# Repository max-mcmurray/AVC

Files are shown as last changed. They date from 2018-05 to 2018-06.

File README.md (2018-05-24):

# Readme:

### Week 1:

- [x] **[All]**: Make GitHub accounts and get plan done
- [x] Josh: Determine formatting for AV code
- [x] Penny: Arrange team meetings
- [x] Penny: Make draft of plan into the final copy
- [x] Toby, Ben: Get basic build of AV planned/put together
- [x] Max: Set up GitHub
- [x] Ben: Make GitHub account

### Week 2:

- [ ] ~~**[All]**: Book CO242A every Thursday~~ This is no longer needed
- [x] Josh: Program ~~sensors and~~ basic movement into AV - Sensors have not yet been added to the AV
- [x] Josh: Program and test the completion of quadrant 2
- [x] Josh: Assign methods to each member of the group
- [x] Toby, Ben: Refine build of AV
- [x] Ben: Program methods for basic movement
- [x] Penny: Get everyone organised and plan for next week
- [x] Penny: Document progress
- [x] Max: Update GitHub with developments

### Week 3:

- [x] Josh: Ensure AV can complete quadrants 1, 2 and 3
- [x] Josh: Test methods as completed by other members
- [x] Penny: Assess team member progress, organise team meeting and plan for next week
- [x] Penny: Write method to open gate
- [x] Penny: Document progress to date
- [x] Max: Update GitHub with development and check over AV design
- [x] Max: Write method to complete line maze
- [x] Toby, Ben: Add sensors to the AV build
- [x] Toby, Ben: Finish the AV build with all the required parts
- [x] Toby: Write method to complete walled maze

### Week 4:

- [x] Josh: Ensure AV can complete course, finalise and optimise code
- [x] Penny: Assessing full team progress against expected results.
- [x] Penny: Implement necessary changes. Bug testing and debugging code
- [x] Max: Update GitHub with development and test AV thoroughly in maze
- [x] Toby, Ben: Make adjustments and finalise AV build

### Week 5:

- [ ] **[All]**: Complete final test of AV - Five attempts and fifteen minutes to complete
- [ ] **[All]**: Put results in report

### Week 6:

- [ ] **[All]**: Continue writing report

### Week 7:

- [ ] **[All]**: Hand in report

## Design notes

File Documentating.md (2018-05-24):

### 03/05
- Created design for base
- Printed base
- Printing of base failed (fell over in the printer)

### 04/05
- Team meeting to prepare and finish AVC plan

### 05/05 12.20
- Discussed methods in code and general 
- Created outline of methods
- Josh wrote goForward
- Josh created makefile
- Changed GitHub to use one branch
- Ben wrote turnLeft
- Penny improved plan
- Josh wrote detectLine
- Toby wrote detectLineToby
- Josh wrote turnRight
- Josh wrote pivotLeft

### 07/05 
- Ben attached the poles connecting the motherboards
- Ben attached the base to the motherboards
- Ben attached the left and right wheels to the base
- The camera was connected to the top base
- The marble holder was printed

### 09/05 
- Attached the marble holder to the base
- Testing basic movement: functionality of the left and right motor
- Josh and Toby modified code to enable some movement throughout maze
- Battery holder was connected to the top base 
- Testing the robot on the maze and debugging issues 
- Right motor is not functioning properly 
- Right motor problem has been fixed
- Testing code on robot and making adjustments to fix errors
- Re-testing the robot on the maze using modified code
- Errors were identified both in code and in hardware: Initially, we thought the robot had followed the white line but could not correct itself when the colour black was scanned by the camera. We concluded that our code needed to be altered (by decreasing the int defaultMicroSec and int defaultSpeed) in order for the robot to change direction in time. After multiple testing and debugging, we reached the final conclusion that in fact one of the motors is slower than the other and that there were errors in our code
- Re-testing the robot on the maze using modified code: The robot followed the white line but turned at a slow speed and went off track but could not correct itself
- Re-tested the robot on the maze using modified code: (EXTREME PROGRESS) The robot followed the white line at a slow speed and could turn at corners properly (without going off track) after camera angle was changed. 
- Re-tested the robot on the maze using modified code: The sample speed was changed but the robot was moving extremely slow on the maze. 
- Re-tested the robot on the maze using modified code: The sample speed, defaultSpeed and other speed were adjusted multiple times. The robot followed the white line properly at a slightly faster pace. More soldering needs to be done. 

### 10/05
- Attached the switch to the battery and base
- Applied modified code to robot
- Testing the robot on the maze: Speed is too slow therefore the robot isn't moving. The defaultSpeed and sample speed have been adjusted. 
- Re-testing the robot on the maze: Sample speed is too slow therefore the robot isn't reading the white line fast enough for the speed it is moving at. The sample speed has been adjusted. 
- Re-testing the robot on the maze: Turn speed is too fast but defaultSpeed is ok. The robot is turning too fast for the defaultSpeed therefore it is going off track. Adjustment must be made to turn speed. 
- Re-testing the robot on the maze: (EXTREME DRAWBACK) Adjustments have been made but the robot is no longer following the white line. defaultSpeed and sample speed has been adjusted back to the original values.
- Re-testing the robot on the maze: The robot can now follow the white line but not as precisely as before. Improvements need to be made in order for the robot to correct itself (reverse etc.) when the camera has scanned black. 
- Re-testing the robot on the maze: The robot can follow the white line properly but at certain bends in the maze, the robot cannot turn fast enough therefore the turn speed needs to be increased slightly. 
- Re-testing the robot on the maze: The robot follows the line at a moderate speed but at certain bends in the maze, the robot only sees black therefore it gets confused. Modification has been made in order for the robot to correct itself and reverse when black is detected by the camera.
- Re-testing the robot on the maze: The robot is reversing when required but is not reversing enough therefore the reverse time needs to be increased.
- Re-testing the robot on maze: The robot is reversing still but the reverse speed needs more power therefore the reverse speed needs to be adjusted and the defaultSpeed is increased. 
- Re-testing the robot on maze: The robot is moving through the maze but the turn is too wide therefore the turn speed needs to be adjusted back to our previous value.
- Re-tesing the robot on maze: The robot moved through the maze and turned correctly but the reverse time needs to be increased.
- Re-testing the robot on maze: The robot corrects it self well and breaks at max white but the turn is too wide therefore the turn speed and reverse speed needs to be adjusted. 
- Re-testing the robot on maze: (EXTREMELY GOOD RUN) The robot turns better and corrects itself properly but the turn is still quite wide therefore the defaultSpeed needs to be adjusted for the inside wheel speed.
- Re-testing the robot on maze: (PERFECT RUN) The robot is turning extremely well at a lower speed. Begin programming next part ----> 

### 14/05

- Testing the code to open the first gate
- Adjusting speeds in order for the robot to move and take bends in the maze smoothly
- The gate is opening and the robot is moving through it at an appropriate time. The robot then moves through the maze smoothly.

### 15/05

- Compiled different versions of code and tested it the robot on the maze
- Writing code for quadrant 3: beginning with the code that makes the robot turn at a right angle which includes establishing the values for each variable that is used
- Adjusting the time of the turn so it doesn't turn too fast or too slow
- Testing the robot on maze: The robot is continuously making a 360 degree turn therefore code needs to be looked at again and adjustments need to be made. 

### 16/05

- Cleaned up code so that it is systematic and easy to follow
- Writing code so that the robot stops at the orange line and also clearly makes left and right turns when required
- (EXTREMELY PROMISING) Test run to see if the robot correctly makes left and right turns when required. Adjustments need to be made to the pivotSpeed and defaultSpeed
- (EXTREMELY EXTREMELY PROMISING) The robot is turning fairly correctly when required now we need to put together the code with the master copy so that it runs the maze up to the end of Quadrant 3
- Minor setback after code was put together - robot isn't turning properly like the previous run therefore adjustments are being made to motor speed
- (HIGHLY PROMISING) The robot is moving correctly but the right and left turns are slightly off but the robot has reached the end
- (SUCCESSFUL RUN) The robot is moving correctly from the beginning of the maze to the end of Quadrant 3.

### 18/05

- Printing out the parts to connect the sensors to the robot
- Attaching the front sensor to the robot
- Writing code so that the robot stops at the orange line

### 22/05 

- The sensors are being attached to the robot 
- Testing the sensors

### 23/05

- Originally there were 3 sensors connected to the robot, all of which are long-range sensors. After testing them out, we reached the conclusion that the robot would need one long-range sensor in the front and two-range sensors on the sides in order to move through the maze. 
- The new sensors have been attached to the robot and code for the maze is being tested
- The robot is moving but continuously turns left and hits the wall 
- We are currently stuck in a deep dark hole. Every member is feeling all types of confused. The problem is hard to identify. 
- The plan is to add back sensors to the robot tomorrow and hope for the best

### 24/05

- The plan was to add back sensors to the robot but today we decided to code without them
- Code for Quadrant 4 is successful: minor tweaks have been made to speed so that the robot moves fast and efficiently through the maze
- The full code has been tested on the maze multiple times and we have had many SUCCESSFUL attempts
- The switch has been attached to the top of the robot 
- THRASHER GOT US 100% YAY!

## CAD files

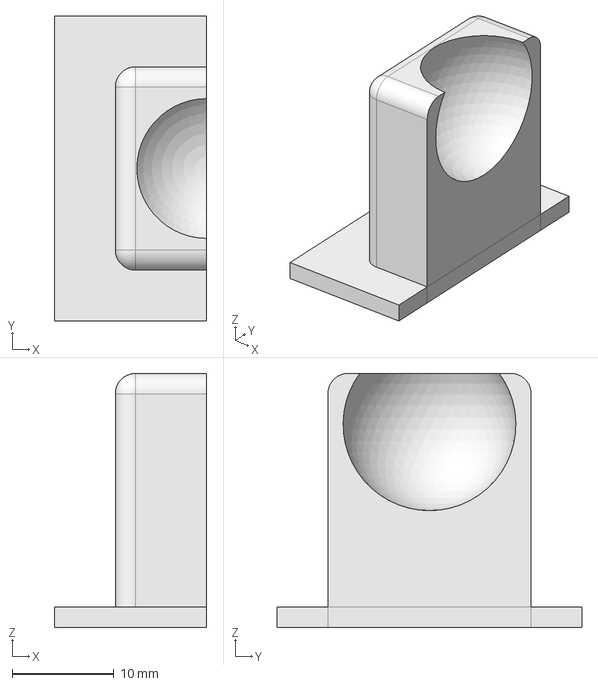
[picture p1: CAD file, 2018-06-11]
3D/Marble-Holder.fcstd
15.0 x 30.0 x 25.0 mm

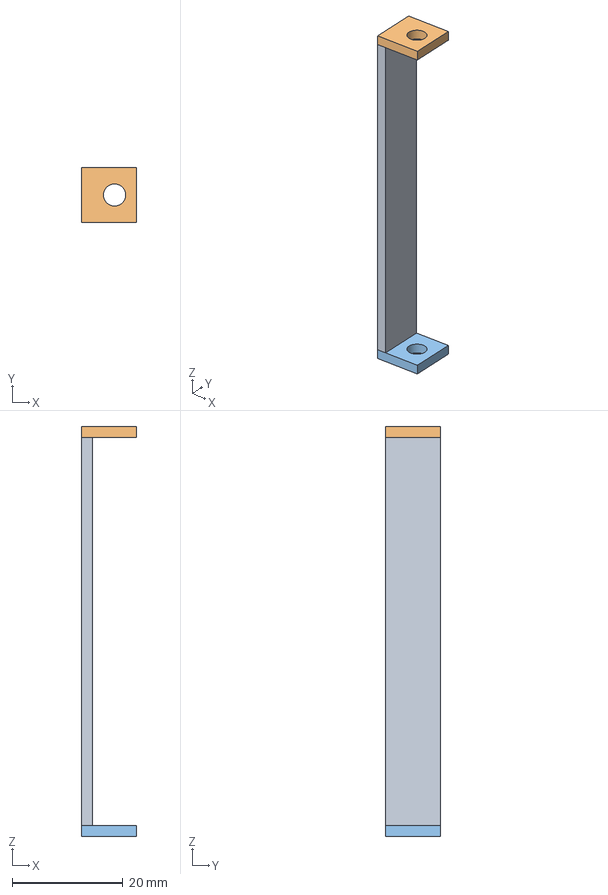
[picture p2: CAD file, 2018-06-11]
3D/IR-Holder-side.fcstd
10.0 x 10.0 x 74.0 mm

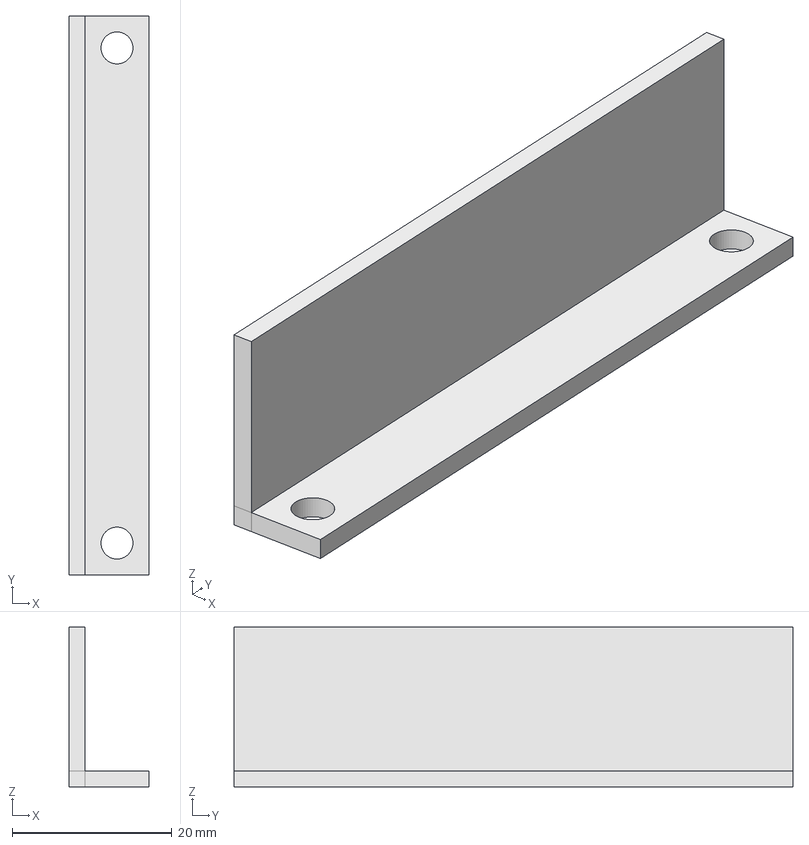
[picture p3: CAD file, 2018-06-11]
3D/IR-Holder-front.fcstd
10.0 x 70.0 x 20.0 mm

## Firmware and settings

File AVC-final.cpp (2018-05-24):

//This program is the intellectual property of TriTeam.
//This program was programmed by Joshua Hindley, Ben Robertson, Max McMurray, Penny Peneueta and Toby Stayner

#include <stdio.h>
#include <time.h>
#include <exception>
#include "E101.h"

/////////////////////////////////////////////////////////////////////
///////////////////////////// VARIABLES /////////////////////////////
/////////////////////////////////////////////////////////////////////

//motor port numbers
int leftMotor = 1;
int rightMotor = 2;

//picture variables
int width = 319;
int height = 239;
int rowToScan = height/2;
int columnToScan = width/2;

//variables for the speed
int straightSpeed = -50;
int reverseSpeed = 50;
int insideWheelSpeed = -25;
int turningWheelSpeed = -60;

//variable for the time (sleep1)
int defaultSec = 0;
int defaultMicroSec  = 2000; 	// 2ms or 0.002 seconds 
int reverseMicroSec = 500000;	// 500ms or 0.5 seconds

//variables for the minimum and maximum color
int maxMin[2];

//variables for determining when to reverse or change quadrant
int blackValue = 100;
int whiteValue = 150;

//variables for pivoting
int rightAngleMSec = 400000; 	// 400ms or 0.4 seconds
double pivotSpeed = -60;

//declaration of all the methods
void openStartGate();
void detectLine();
void lineMaze();
void goForward(int forwardMicroSec);
void reverse(int sec, int microsec);
void turnLeft(int sec, int microsec);
void turnRight(int sec, int microsec);
void pivotLeft(int sec, int microsec, double speed);
void pivotRight(int sec, int microsec, double speed);
double getAmountToTurn(int threshold);
void findMaxAndMin();
void stop();
void navigateWalledMaze();
void centreWallMaze();


/////////////////////////////////////////////////////////////////////
////////////////////////////// METHODS //////////////////////////////
/////////////////////////////////////////////////////////////////////

//main method. determines which method to call
int main()
{
	init();
	//call the openStartGate method to complete quadrant 1
	openStartGate();
	sleep1(0, 200000);
	//call the detectLine method to complete quadrant 2
	detectLine();
	//openStartGate();
	goForward(200000);
	//call the lineMaze method to complete quadrant 3
	lineMaze();
	//openStartGate();
	navigateWalledMaze();
	stop();
	return 0;
}

//opens the gate at the start of the course, completing the first quadrant
//written by Penny Peneueta
void openStartGate()
{
	//variables for connecting to the server
	char server_addr[15] = "130.195.6.196";
	int port = 1024;
	char message[24] = "Please";
	
	//connects to the server, sends a message, receives a message and sends the received message
	connect_to_server(server_addr, port);
	send_to_server(message);
	receive_from_server(message);
	send_to_server(message);
	//prints to the console
	printf("Gate opened.\n");
	printf("******************Quadrant 1 completed.\n\n");
}

//finds where the white line is and calls methods to move the AV stay on the line
//written by Joshua Hindley
void detectLine()
{
	try{
		while(true)
		{
			findMaxAndMin();
			//if all the rowToScan pixels are black
			if(maxMin[0] < blackValue)
			{
				reverse(defaultSec, reverseMicroSec);
			}
			//if all the rowToScan pixels are white
			else if(maxMin[1] > blackValue)
			{
				//print to console
				printf("******************Quadrant 2 completed\n\n");
				return;
			}
			else
			{
				//calculates the threshold and calls the getAmountToTurn method to determine the amount to turn
				int threshold = (maxMin[0] + maxMin[1]) / 2;
				double amountToTurn = getAmountToTurn(threshold);
				if(amountToTurn <= 1000 && amountToTurn >= -1000) //CHANGE THIS VALUE TO CHANGE HOW OFTEN IT TURNS
				{
					goForward(defaultMicroSec);
				}
				else if(amountToTurn > 1000) //turn to the right
				{		
					turnRight(defaultSec, defaultMicroSec);
				}
				else //turn to the left
				{	
					turnLeft(defaultSec, defaultMicroSec);
				}
			}
		}
	}
	catch(const std::exception& e){
		printf("An error occured!\n");
	}
	//set the motor's speeds to zero
	stop();
}

//Follows lines in the form of a maze
//Written by Max 
void lineMaze() 
{
	bool justTurned = false;
    try{
		while(true)
		{
			//set the max and min values
		   	findMaxAndMin();
			//if all the pixels are black
		    if(maxMin[0] < blackValue + 25)
		    {
				if (!justTurned) 
				{
					//pivots to the left
			    	pivotLeft(0, rightAngleMSec / 2, pivotSpeed);
			    	justTurned = true;
			    	sleep1(0, 500000);
				}
				else 
				{
					//pivots to the right twice
			   		pivotRight(0, rightAngleMSec / 2, pivotSpeed);
			    	sleep1(0, 500000);
			    	pivotRight(0, rightAngleMSec / 2, pivotSpeed);
			    	justTurned = false;
			    	sleep1(0, 500000);
				}
		    }
		   	else
		    {
				justTurned = false;
				//calculates the threshold and calls the getAmountToTurn method to determine the amount to turn
				int threshold = (maxMin[0] + maxMin[1]) / 2;
				double amountToTurn = getAmountToTurn(threshold);
				if((amountToTurn <= 20) & (amountToTurn >= -20)) 
				{
			    	goForward(defaultMicroSec);			   
				}
				else if(amountToTurn > 20) //turn to the right
				{
			    	turnRight(defaultSec, defaultMicroSec);			 
				}
				else //turn to the left
				{
			   		turnLeft(defaultSec, defaultMicroSec);
				}
		    }
			//if the centre pixel of the image is orange
		    if( (get_pixel(160, 120, 0) > 150) & (get_pixel(160,120,1) < 80) & (get_pixel(160, 120, 2) < 70))
		    {
				//print to the console
				printf("******************Quadrant 3 completed\n");
				//set the motor speeds to zero
				stop();
				return;
		    }
		}
	}
	//if an error occurs
    catch(const std::exception& e)
	{
		printf("An error occured\n");
	}
	//set the motor speeds to zero
	stop();
}

//follows the left wall of the maze, completing the final quadrant
//written by Toby Stayner

int frontThreshold = 350; // AV considers the robot has a wall in front anything larger than this
int wallThreshold = 450; // AV considers the robot has a wall either side anything larger than this
int noiseConstant; // amount of leeway before the left sensor is no longer considered equal to the right sensor
int forwardAfterTurn = 250000; // amount of time (microsecs) the AV should continue travelling forward once it has made a turn

int left_sensor = 2; // the number ports that the wires are physically connected to
int front_sensor = 1;
int right_sensor = 0;
int adc_reading_left;
int adc_reading_front;
int adc_reading_right;
bool seenRed = false;

void navigateWalledMaze()
{
	printf("Beggining***\n");
	goForward(500000);
	try{
		while(1)
		{
			adc_reading_left = read_analog(left_sensor); // read the sensor values and store them
			adc_reading_front = read_analog(front_sensor);
			adc_reading_right = read_analog(right_sensor);

			take_picture();
			//if the centre pixel of the image is red
		    if((get_pixel(160, 120, 0) > 200) & (get_pixel(160,120,1) < 100) & (get_pixel(160, 120, 2) < 150) & !seenRed)
		    {
				seenRed = true;
				goForward(900000);
				stop();
				adc_reading_front = read_analog(front_sensor);
				//if gate is open
				if((adc_reading_front < 75))
				{
					//while gate is open
					while(adc_reading_front < 75)
					{
						//wait for gate to close
						adc_reading_front = read_analog(front_sensor);
					}
				}
				//while gate is closed
				while(adc_reading_front > 75)
					{
						//wait for gate to open
						adc_reading_front = read_analog(front_sensor);
					}
		    }
			// if there are nearby walls on both sides and can go forward
			if((adc_reading_front < frontThreshold))
			{
				printf("Forward.\n");
				centreWallMaze();
			}

			// if there is a path on the left only
			else if((adc_reading_left > wallThreshold) & (adc_reading_front > frontThreshold))
			{ 
				printf("******************************Turning left.\nLeft: %d\nRight: %d\n", adc_reading_left, adc_reading_right);
				pivotLeft(0, rightAngleMSec, pivotSpeed);
				sleep1(0, 100000);
				goForward(forwardAfterTurn);
			}
			// if there are nearby walls on both sides and cannot go forward
			else if((adc_reading_left < wallThreshold) & (adc_reading_right < wallThreshold) & (adc_reading_front > frontThreshold))
			{
				printf("Dead end detected! Turning around.\n");
				pivotRight(0, rightAngleMSec, pivotSpeed);
				sleep1(0, 100000);
				pivotRight(0, rightAngleMSec, pivotSpeed);
				sleep1(0, 100000);
			}
			else
			{
				reverse(0, 200000);
			}
		}
	}
	catch(const std::exception& e)
	{
		printf("An error occured\n");
	}
	//set the motor speeds to zero
	stop();
 
}

void centreWallMaze()
{
	try
	{
		if((adc_reading_right < wallThreshold))
		{
			printf("********Turning Left\n");
			turnLeft(defaultSec, defaultMicroSec*40);
		}
		else if((adc_reading_right > wallThreshold))
		{
			printf("********Turning Right\n");
			turnRight(defaultSec, defaultMicroSec*40);
		}
		goForward(defaultMicroSec);
		sleep1(0, 10000);
	}
	catch(const std::exception& e)
	{
		printf("An error occured\n");
	}
	//set the motor speeds to zero
	stop();
}

//moves the AV forward
//written by Ben Robertson
void goForward(int forwardMicroSec)
{
	set_motor(leftMotor, straightSpeed);
	set_motor(rightMotor, straightSpeed);
	
	sleep1(defaultSec, forwardMicroSec);
}

//revereses the robot
//written by Ben Robertson
void reverse(int sec, int microSec)
{
	set_motor(leftMotor, reverseSpeed);
	set_motor(rightMotor, reverseSpeed);
	
	sleep1(sec, microSec);
}

//turns the AV left by moving one wheel
//written by Ben Robertson
void turnLeft(int sec, int microsec)
{
	set_motor(leftMotor, insideWheelSpeed);
	set_motor(rightMotor, turningWheelSpeed);
	
	sleep1(sec, microsec);
}

//turns the AV right by moving one wheel
//written by Ben Robertson
void turnRight(int sec, int microsec)
{
	set_motor(leftMotor, turningWheelSpeed);
	set_motor(rightMotor, insideWheelSpeed);
	
	sleep1(sec, microsec);
}

//pivots the AV to the left at a point
//written by Ben Robertson
void pivotLeft(int sec, int microsec, double speed)
{
	set_motor(leftMotor, -(speed + 2));
	set_motor(rightMotor, (speed + 2));
	
	sleep1(sec, microsec);
	
	stop();
}

//pivots the AV to the right at a point
//written by Ben Robertson
void pivotRight(int sec, int microsec, double speed)
{
	set_motor(leftMotor, speed - 2);
	set_motor(rightMotor, -(speed - 2));
	
	sleep1(sec, microsec);
	
	stop();
}

//finds and returns the maximum and minimum color
//written by Joshua Hindley
void findMaxAndMin()
{
	//set the max and min values
	int maximum = 0;
	int minimum = 255;
	take_picture();
	for(int i = 0; i < 320; i++)
	{
		//gets a pixel from the centre row (rowToScan) of the picture
		int pix = get_pixel(rowToScan, i, 3);
		//stores the max and min pixel value
		if(pix < minimum)
			minimum = pix;
		if(pix > maximum)
			maximum = pix;
	}
	maxMin[0] = maximum;
	maxMin[1] = minimum;
}

//calculates and returns the amount to turn
//written by Joshua Hindley
double getAmountToTurn(int threshold)
{
	int weight = -160;
	double amountToTurn = 0;
	for(int i  = 0; i < 320; i++)
	{
		//gets a pixel from the centre row (rowToScan) of the picture
		int pixelValue = get_pixel(rowToScan, i, 3);
		//if the pixel is darker than the threshold
		if(pixelValue < threshold)
			pixelValue = 0;
		//if the pixel is lighter than the threshold
		else
			pixelValue = 1;
		//increases (or decreases where weight is negative) the amount to turn
		amountToTurn += (weight * pixelValue);
		weight++;
		if(weight == 0)
			weight = 1;
	}
	//returns the amountToTurn
	return amountToTurn;
}

void stop() {
	set_motor(leftMotor, 0);
	set_motor(rightMotor, 0);
}

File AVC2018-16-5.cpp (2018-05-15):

//This program is the intellectual property of TriTeam.
//This program was programmed by Joshua Hindley, Ben Robertson, Max McMurray, Penny Peneueta and Toby Stayner

#include <stdio.h>
#include <time.h>
#include <exception>
#include "E101.h"
/*
****************************************************************************************
*****************************LOWER THE AXIS*********************************************
****************************************************************************************
*/
int scope = 5;
int width = 319;
int height = 239;
int leftMotor = 1;
int rightMotor = 2;		// May be wrong way around
int straightSpeed = -50;	//CHANGE THIS TO MAKE GOING STRAIGHT WORK PROPERLY
int insideWheelSpeed = -25;
int turningWheelSpeed = -60;
int reverseSpeed = 50;
int defaultSec = 0;
int defaultMicroSec  = 2000; 	//2.5ms or 0.0025 seconds 
int reverseMicroSec = 500000;				
int rowToScan = height / 2;
int lowerRowToScan = height - 10;
int columnToScan = width/2;	
int max = 0;
int min = 255;
//int timesToRun = 4500;
int blackValue = 100;
int whiteValue = 150;

//**************************************************************************************
int rightAngleMSec = 400000;
double pivotSpeed = -60;
//***************************************************************************************

void detectLine();
void turnLeft(int sec, int microsec);
void turnRight(int sec, int microsec);
void goForward(int forwardMicroSec);
void reverse(int sec, int microsec);
void pivotLeft(int sec, int microsec, double speed);
void pivotRight(int sec, int microsec, double speed);

//opens the gate at the start of the course, completing the first quadrant
void openStartGate()
{
	char server_addr[15] = "130.195.6.196";
	int port = 1024;
	char message[24] = "Please";
	
	connect_to_server(server_addr, port);
	printf("Connecting to server.\n");
	send_to_server(message);
	//printf("Sending message: %s\n", message);
	receive_from_server(message);
	//printf("Received password: %s\n", message);
	send_to_server(message);
	printf("Sending password.\n");
	printf("Gate opened.\n");
	printf("Quadrant 1 completed.\n\n");
}

//finds where the white line is and calls methods to move the AV stay on the line
//written by Joshua Hindley
void detectLine()
{
	try{
		while(true)
		{
			max = 0;
			min = 255;
			take_picture();
			for(int i = 0; i < 320; i++)
			{
				int pix = get_pixel(rowToScan, i, 3);
				if(pix < min)
					min = pix;
				if(pix > max)
					max = pix;
			}
			if(max < blackValue)
			{
				reverse(defaultSec, reverseMicroSec);
			}
			else if(min > blackValue)
			{
				printf("*****BROKEN!*****\n");
				printf("Quadrant 2 completed");
				break;
			}
			else
			{
				int threshold = (max + min) / 2;
				int weight = -160;
				double amountToTurn = 0;
				for(int i  = 0; i < 320; i++)
				{
					int pixelValue = get_pixel(rowToScan, i, 3);
					if(pixelValue < threshold)
						pixelValue = 0;
					else
						pixelValue = 1;
					amountToTurn += (weight * pixelValue);
					weight++;
					if(weight == 0)
						weight = 1;
				}
				if(amountToTurn <= 20 && amountToTurn >= -20) //CHANGE THIS VALUE TO CHANGE HOW OFTEN IT TURNS
				{
					goForward(defaultMicroSec);
				}
				else if(amountToTurn > 20) //turn to the right
				{		
					turnRight(defaultSec, defaultMicroSec);
				}
				else //turn to the left
				{	
					turnLeft(defaultSec, defaultMicroSec);
				}
			}
		}
	
	}
	catch(const std::exception& e)
	{
		printf("An error occured\n");
	}
	set_motor(leftMotor, 0);
	set_motor(rightMotor, 0);
}

//For the third quadrant written by Max <3
void lineMaze() {
	int times = 0;
	while (1){
		
		//0 = top line. Proceeding numbers go clockwise
		int maxs[4] = {0, 0, 0, 0};
		int mins[4] = {255, 255, 255, 255};
		take_picture();
		
		//For line 0
		for (int pixel = 0; pixel < width; pixel++) {
			int pixelValue = get_pixel(0, pixel, 3);
			if (pixelValue < mins[0]) {
				mins[0] = pixelValue;
			}
			if (pixelValue > maxs[0]) {
				maxs[0] = pixelValue;
			}
		}
		
		//For line 1
		for (int pixel = 0; pixel < height; pixel++) {
			int pixelValue = get_pixel(pixel, width, 3);
			if (pixelValue < mins[1]) {
				mins[1] = pixelValue;
			}
			if (pixelValue > maxs[1]) {
				maxs[1] = pixelValue;
			}
		}
		
		//For line 2
		for (int pixel = 0; pixel < width; pixel++) {
			int pixelValue = get_pixel(height, pixel, 3);
			if (pixelValue < mins[2]) {
				mins[2] = pixelValue;
			}
			if (pixelValue > maxs[2]) {
				maxs[2] = pixelValue;
			}
		}
		
		//For line 3
		for (int pixel = 0; pixel < height; pixel++) {
			int pixelValue = get_pixel(pixel, 0, 3);
			if (pixelValue < mins[3]) {
				mins[3] = pixelValue;
			}
			if (pixelValue > maxs[3]) {
				maxs[3] = pixelValue;
			}
		}
		for(int i = 0; i < 4; i++)
		{
			printf("Line %d:\n", i);
			printf("Max: %d\n", maxs[i]);
			printf("Min: %d\n\n", mins[i]);
		}
		
		//If given the opportunity to turn left then do so
		if (maxs[3] > whiteValue) {
			while (get_pixel(0, height, 3) < whiteValue) {
				goForward(5000);
				set_motor(leftMotor, 0);
				set_motor(rightMotor, 0);
				take_picture();
            }
            pivotLeft(0, rightAngleMSec, pivotSpeed);
            goForward(reverseMicroSec);
		}
		
		//If can't turn left but can go forward then go forward
		else if (maxs[0] > whiteValue) {
		    goForward(reverseMicroSec);
		}
		
		
		//Turn right if can
		else if (maxs[1] > whiteValue) {
			//goForward
			pivotRight(0, rightAngleMSec, pivotSpeed);
			goForward(reverseMicroSec);
		}
		
		//Must be at dead end so turn round
		else {
			pivotRight(0, rightAngleMSec, pivotSpeed);
			pivotRight(0, rightAngleMSec, pivotSpeed);
			goForward(reverseMicroSec);
		}

		//adjustToLine();//Mayyyyyyybe write this or make it work
		times++;
	}
}


//moves the AV forward
//written by Joshua Hindley
void goForward(int forwardMicroSec)
{
	//printf("Going forward.\n");
	set_motor(leftMotor, straightSpeed);
	set_motor(rightMotor, straightSpeed);
	
	sleep1(defaultSec, forwardMicroSec);
	
	//set_motor(leftMotor, 0);
	//set_motor(rightMotor, 0);
}

//turns the AV left by moving one wheel
//written by Ben Robertson
void turnLeft(int sec, int microsec)
{
	set_motor(leftMotor, insideWheelSpeed);
	set_motor(rightMotor, turningWheelSpeed);
	
	sleep1(sec, microsec);

	//set_motor(rightMotor, 0);
	//set_motor(leftMotor, 0);
}

//turns the AV right by moving one wheel
//written by Joshua Hindley
void turnRight(int sec, int microsec)
{
	set_motor(leftMotor, turningWheelSpeed);
	set_motor(rightMotor, insideWheelSpeed);
	
	sleep1(sec, microsec);
	
	//set_motor(leftMotor, 0);
	//set_motor(rightMotor, 0);
}

void reverse(int sec, int microSec)
{
	set_motor(leftMotor, reverseSpeed);
	set_motor(rightMotor, reverseSpeed);
	
	sleep1(sec, microSec);
}
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
